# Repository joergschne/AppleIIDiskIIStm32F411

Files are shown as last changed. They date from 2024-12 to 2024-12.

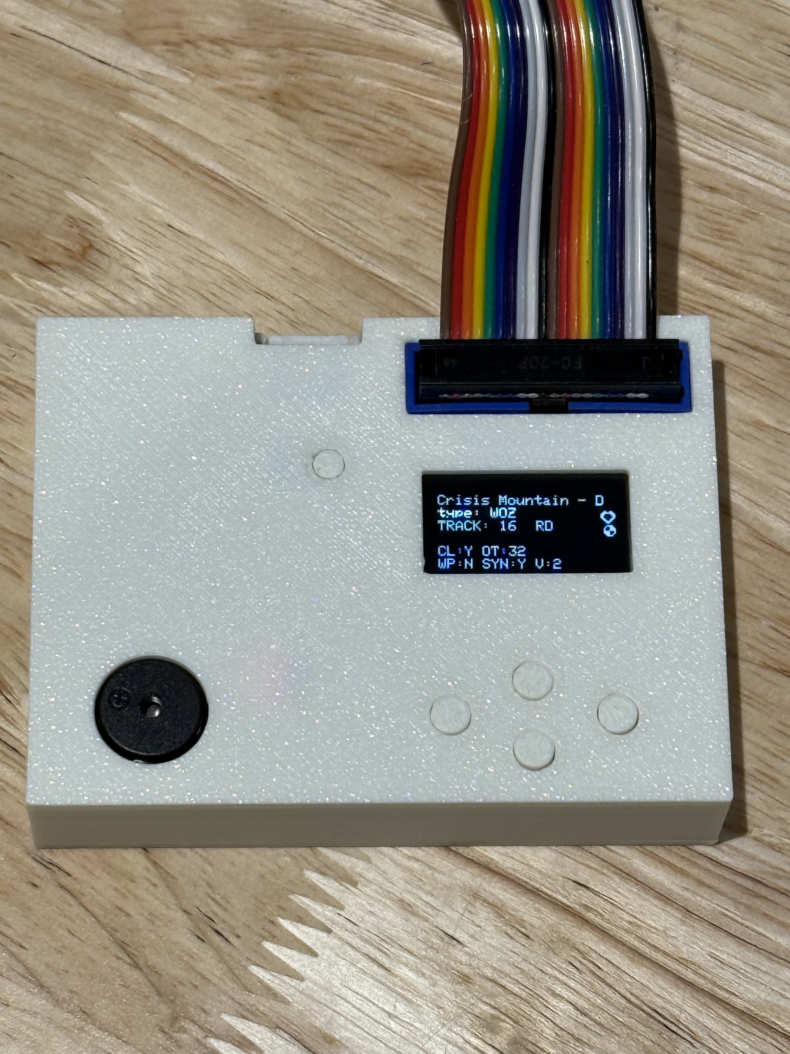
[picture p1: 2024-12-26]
resources/CASE.jpeg

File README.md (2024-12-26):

# SmartDisk II for Apple II

## Apple II STM32 based Hardware DISKII EMULATOR

This project is about an Apple II Disk II hardware emulator capable of reading / writing disk image from/to SDCARD.

This hardware emulator tries to replicate the behaviour of a real DISK II and thus should pass the copy protection on guenine disk images.

The project is still in beta mode, progress thread is on [AppleFritter Apple II Disk emulator using STM32]( https://www.applefritter.com/content/apple-ii-disk-emulator-using-stm32).



** If you decide to build one, please note that hardware design might evolve and new software releases might not work with the current hardware design. ** 
 
This project relies on a STM32F411(BlackPill) with SDIO Port.

## Project structre ##

| Directory | Description  |
|:---|:---|
|  ./gerber  | gerber release to produce PCB |
| ./hardware | kicad project |
| ./core | firmware source code |
| ./Middleware | libraries used |
| ./FATFS | fatfs wrapper  |
| ./doc | documentation used as reference  |
| ./3DPrintCase | 3D print file & Fusion 360 source to print case  |

## IMPORTANT NOTE ##

The ST-Link programmer should never be connected at the same time with either USB or the Apple II. The ST-link has some very fragile voltage regulator. 

The J1 PWR located at top right of the PCB enable +5V from the Apple II to the STM32.

Regarding the OLED Screen: becareful of the Power pins order, some version have pin inversed

R1,R2,R3 are not needed.

Before hardware Rev 3 the board is not compatible with IIGS & IIC, trace between IDC pin 5 & 7 needs to be cut

## <!> SDCARD <!> ##

The SDCard must use FAT32 file system must use 64 Sectors of 512 Byte each per cluster.

to format the SDCard under linux use the following command: 

`mkfs.fat -F 32 -s 64 `

Please be careful, Window 10/11 is not formatting the SDCard the right way. 

An config menu option is provided directly in the SmartDisk II to format the SDCard

## Main Features ##

The list of features currently supported in this project:
- Read the content of the SDCard and display the list of images on a 0.96 OLED display based of the ss1306.
- Mount / unmount disk image
- Read mounted image file on Apple II
- Write (experimental)





### Supported Emulation:
| Emulation  | Status
|:---  |:-----|
| DISK II 5.25| YES |
| SMARTPORT HD| YES |

### Supported disk image format:

| format  | read | write |
|:---  |:-----|:---|
| NIC| YES | NO | 
| WOZ 1.0| YES | NO |
| WOZ 2.0| YES | Experimental|
| DSK | YES  | NO |
| PO | YES | NO |

### Copy protection status

| Copy Protection | Status  | 
|:---|:---|
| FAT Track | PASSED |
| Weak Bit  | PASSED | 
| Cross track sync  | PASSED | 
| Half track | PASSED | 
| Data Latch | PASSED | 
| Timing Bits | PASSED |
| E7 | PASSED | 
| Optimal Bit Timing <4uS | PASSED |
| Various Bit Counter | PASSED | 
| SpiraDisc | PASSED | 

## Status of the project ##

The first PCB and software are available for testing purpose only. 

## Release

There are 2 releases type :
- BIN : classic binary to be uploaded via stlink and starting at 0x08000000
- UF2 : first you need to upload via stlink the custom bootloader, and then using USB and double click on NRST button, you can easily drag and drop UF2 release file to the stm32. WARNING if using the bootloader, the flash memory from 0x0800000 to 0x80100000 will become read-only (you need to use st-tool to change the stm32 register to reverse).

## What is coming next ## 

- Creation of a PCB with the STM32 chip directly,
- add root panel and config panel
- Add mkfs in the config panel
- Addition of protection to 20 pin connector inversion,
- Support of dsk,po image format for reading,
- Support of nic,woz 1.x -> 2.1 for writing,
- configuration screen,
- adding USB & UF2 bootlooder firmware update support,
- Remove STM HAL (High Level) driver and move to low level,
- Finalize a stable software.

## Hardware design main principles: ##

- The STM32F4x is preferred compared to the STM32F1 due to CPU Freq, available SRAM >60 kB and for the STM32F411 the use of SDIO. On this project timing is really critical, especially to pass some copy protection.

A DISK II floppy track is about 50.000 Bits, and to be able to read some of the floppy shifting from one track to another should respect some very specific rules.

- After many, many, many iterations and design tests, I decided to use a single track load in memory and to have SDCARD Data Read/Write using a 4bit SDIO port for speed. This way, there is no adjacent track management and complex buffer copy with internal index along with DMA interrupt. The constraints is to use very fast loading capability of the SDIO port (SPI works but with no containgency). 

- The Apple II is expecting data at a very precise pace 1 bit every 4 uS (32*125ns). Multiple options can be considered to perform this:
	- 1/ Using SPI with DMA
	- 2/ Assembly code with CPU cycle calculation & GPIO Bitbanging
	- 3/ Timer interrupt trigger with GPIO Bitbanging (preferred option)

The first option was my initial choice, very simple straight forward, and the CPU using DMA was completly free to do something else while sending data. One of the aspect of the SPI is to send 8 bits (1 Bytes) at a time. When using WOZ 1.0 and WOZ 2.0 the number of bits per track are not aligned with 8 and thus using SPI may (every time on a 36 track disk) introduce bit misalignement and corrupted data. There is no way to have WOZ copy protected image file to work using 8 Bits aligned data stream.

The second option was also tested and gives very poor reliability and was very quickly put aside.

The last one, using TIMER interrupt seems by far to be the best option and enable to free up CPU time to manage the OLED display updates and to other button interrupt. 
Each interrupt, the Read GPIO is bitbang according to the track stream position. The real advantage is to be able to address very easily some specific protection mecanism using fake bit tank. Using timer is also very easy to increase or reduce the space between 2 bit because some games use 3.8 uS instead of 4 uS. The trick is to manage other interrupt priority not to disturb the READ/WRITE Timer process.

- The approach for the writing process is pretty much the same as for the reading process, using a dedicated timer with an overflow every 4us. As writing uses polarity inversion, an internal software XOR is done instead of using external circuitery. Using the SDIO makes it also very easy timing wise to write to SDCard.  

Using this approach with Timers, there is no need to external circuitery and almost everything can be manage from a software standpoint (in the future I might add a 74LS125 to protect the STM32).

Main design on STM32:

Head positionning stepper, managed by external interrupts: 
  - PA0 STEP0, ExtI0
  - PA1 STEP1, ExtI1
  - PA2 STEP2, ExtI2
  - PA3 STEP3, ExtI3

Button: External Interrupt 9-15 with Timer4 as a debouncer
  - PC13 BTN_DOWN
  - PC14 BTN_UP
  - PC15 BTN_ENTR
  - PB12 BTN_RET

SDCARD: SDIO Port with a clock divider by 2 (to keep most of the SDCard working)
  - PB4 DO
  - PA8 D1
  - PA9 D2
  - PB5 D3
  - PA6 CMD
  - PB15 CK

I2C Oled Screen SSD1306
  - PB06 SCL
  - PB07 SDA

UART:
  - PA15 TX
  - PB3 RX

TIMERS:
- TIM2 Timer 2 : Use to Manage the WR_DATA, ETR1 Slave Reset mode to resync with the Apple II  Write Pulse that is 3.958 uS instead of 4uS. Every Rising Edge resync
- TIM3 Timer 3 : Use to Manage the RD_DATA, 
- TIM4 Timer 4 : Internal no PWM, debouncer for the control button

## BOM ## 

| Ref. | Type. |  Ref Supplier  |
|:---|:---|:---|
| Uc1 | STM32F411 (BlackPill) | Aliexpress WeAct Studio 3.0 STM32F411CEU6  |
| U2 | SDCard PushPush GCT MEM2055 / GCT MEM2075  | Mouser 640-MEM20750014001A / LCSC C381084  |
| U8 | SSD1315 I2C 128x64 0.96 OLED |  LCSC C5248080 |
| R1,R2,R3  | Resistor 1K (Optional)  1/4W L6.3mm_D2.5mm_P10.16mm  | Mouser 708-CFF14JT1K00 |
|J1|PWR|Pin Header_1x02 P2.54mm  |
|J2|Apple IDC 2x10P P2.54| LCSC C115249|
|J3|DBG|Pin Header_1x05 P2.54mm  |
|J4|UART|Pin Header_1x03 P2.54mm  |
|J5|TIM|Pin Header_1x03 P2.54mm  |
|J6|STLINK|Pin Header_1x04 P2.54mm  |
|DOWN1,ENTR1,RET1,UP1|6mm 5mm Round Button 50mA Direct Insert 6mm SPST 12V| LCSC C393938
|BZ1|Passive buzzer 12 x 6.0MM P6.5| LCSC C252917

## Software design main principles: ##

The current software version rely on :
- STM32 HAL Driver from STMicro
- FATFS 0.15 (becareful STCUBEMX32 override to version 0.11)
- CJOSN for configuration file (with some tweaks to make FATFS working)
- SSD1306 Lib with DMA

Software Architecture: 

the maximum track size is 13*512*8= 53 248 Bits or 6656 Bytes

2 Unsigned char Buffers are used :
- DMA_BIT_TX_BUFFER[6656];   	// For reading part     
- DMA_BIT_RX_BUFFER[6656];		// For writing part

weakBitTank uint_8 array & fakeBitTank char array are used to manage some copy protection mecanism

### Important Functions ### 

- void TIM3_IRQHandler: Manage the Bitbang of the GPIO port to send track data every 4us (or less depending on the WOZ file configuration) to the Apple II

- void void TIM2_IRQHandler: Manage the data sent from the Apple II for the writing process. It use a software XOR to detect polarity inversion and write 1 or 0 to the DMA_BIT_RX_BUFFER.

- void irqReadTrack: Configure interrupt for Reading 
- void irqWriteTrack: Configure interrupt for Writing

- void getDataBlocksBareMetal(long memoryAdr,volatile unsigned char * buffer,int count): Instead of using FATFS function such as F_OPEN, using direct access to the SDCard using the SDIO port to receive data is faster.

- void setDataBlocksBareMetal(long memoryAdr,volatile unsigned char * buffer,int count): same for the writing process, faster than using FATFS

<!> keep in mind that even if FATFS is not used to read and write to the SDCARD data from/to the Apple II, FATFS is needed to build up the File Allocation Table with the right file address block.

- void processDeviceEnableInterrupt: Interrrupt function used when Apple II change signal on DEVICE_ENABLE PIN to activate or deactivate the DISKII Drive. This signal is active LOW

- void processBtnInterrupt: Manage the 4 BTN press

- void processDiskHeadMoveInterrupt(uint16_t GPIO_Pin): Interrupt function link to the 4 GPIO Stepper motor of the DISKII.

- Main () is orchestring the program execution. 

Please note that you will need to have a STLINK32 to upload the firmware to the STM32F411



## Recommanded reading 

- Woz 2.1 Image file reference
- Woz 1.0 Image file reference
- Tome of copy protection
- Beneath Apple DOS
- Assembly lines
- Understanding the Apple II 
- PoC|GFTO_issue10
- PoC|GFTO_issue11

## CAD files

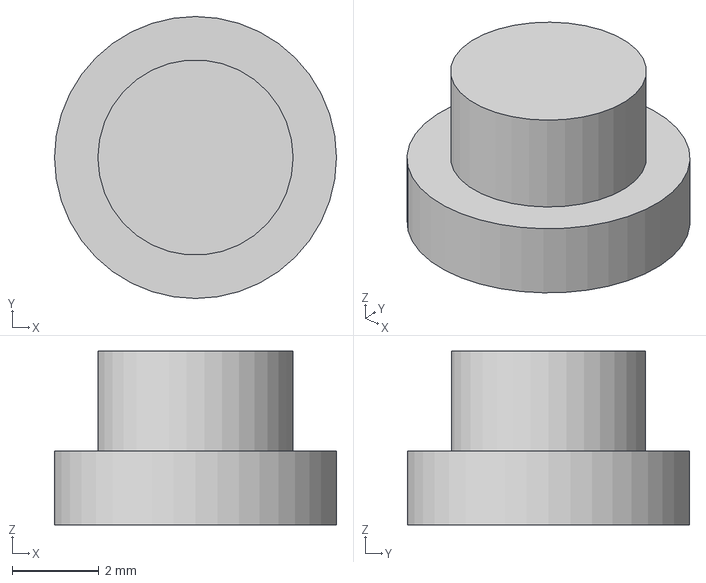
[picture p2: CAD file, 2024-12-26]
3DPrintCase/SmartDiskII button v18.3mf
6.50 x 6.50 x 4.00 mm

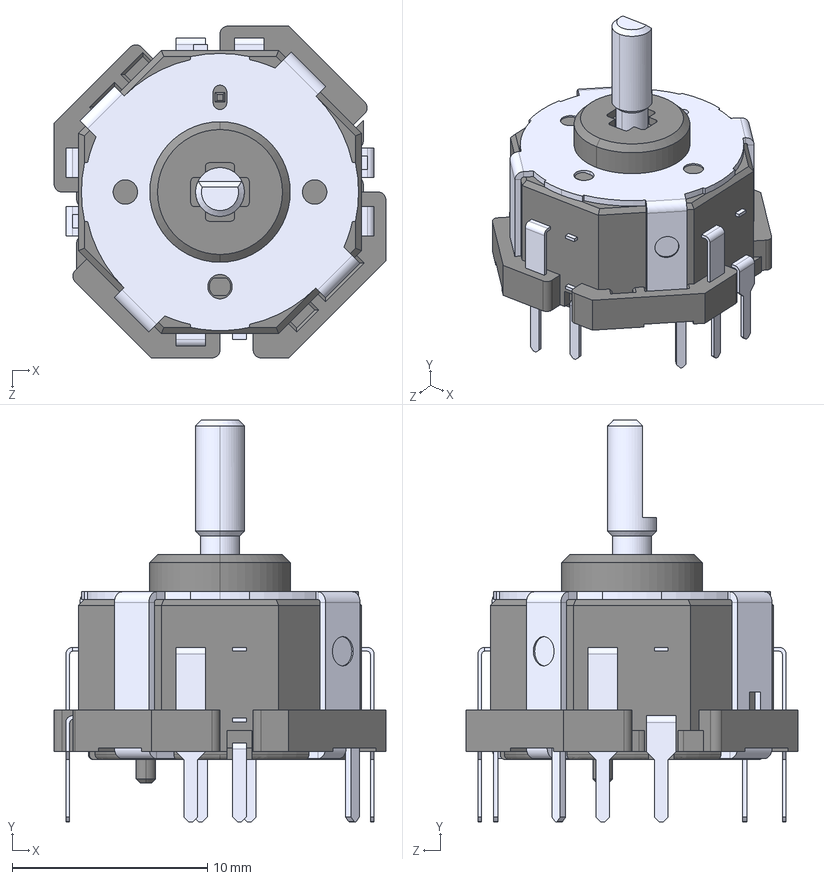
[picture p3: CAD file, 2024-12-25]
Contribute/A2F-Hardware/cad/RKJXT1F42001.step
17.0 x 20.6 x 17.0 mm

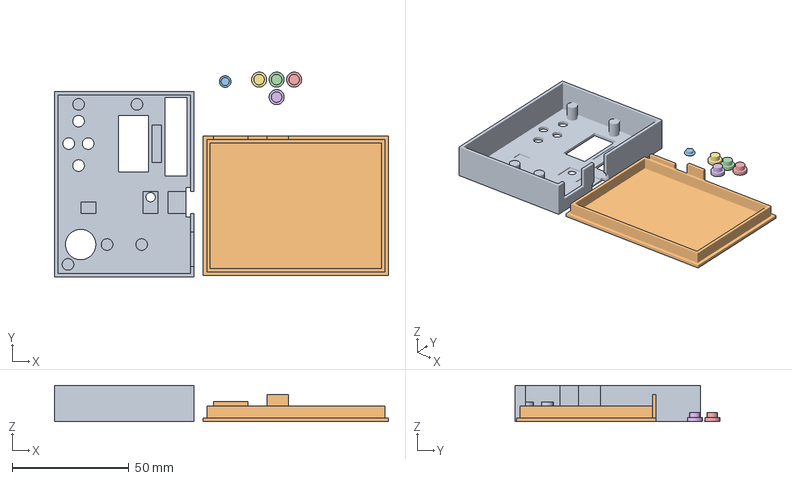
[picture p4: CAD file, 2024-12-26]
3DPrintCase/SmartDiskII Bambulab prj.3mf
142.9 x 87.7 x 15.5 mm
SmartDiskII bottom v18b
couvercle
bouton RESET
bouton x 4

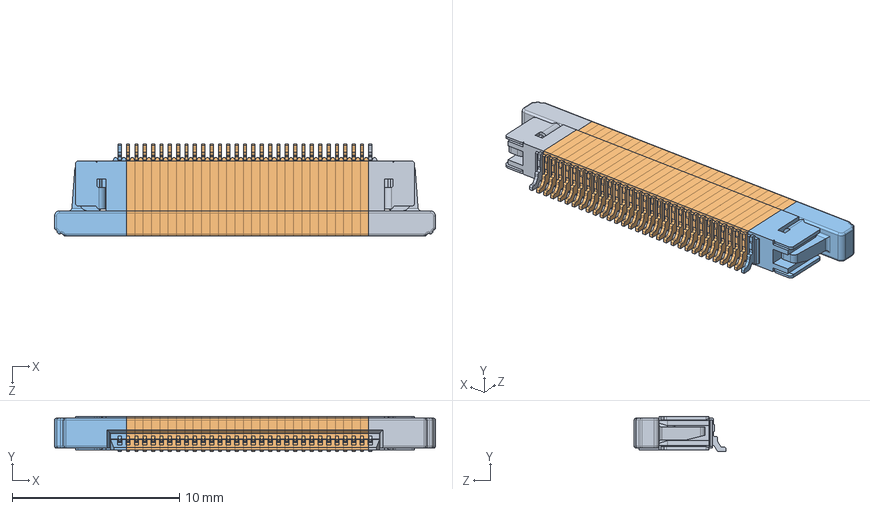
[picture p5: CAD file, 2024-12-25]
Contribute/A2F-Hardware/cad/F32R-1A7H1-11031.step
22.8 x 2.10 x 5.50 mm
F32R_R.STEP
F32R_M.STEP x 29
F32R_L.STEP

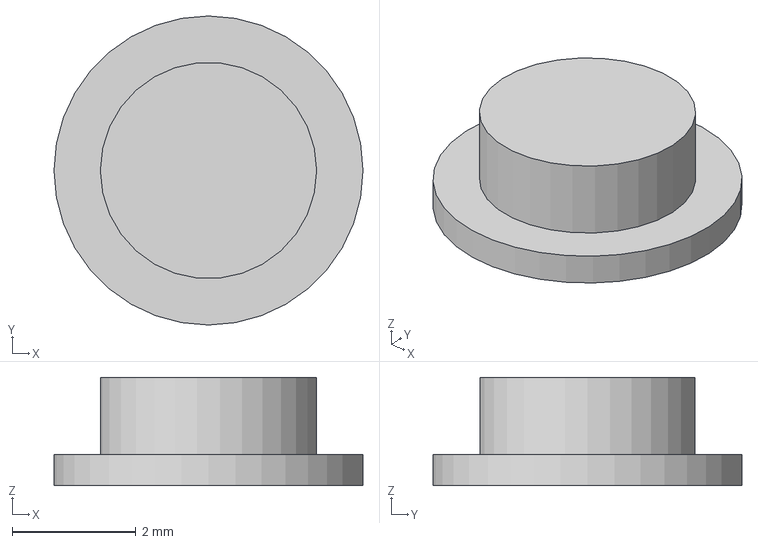
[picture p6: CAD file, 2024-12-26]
3DPrintCase/SmartDiskII button reset v18.3mf
5.00 x 5.00 x 1.75 mm

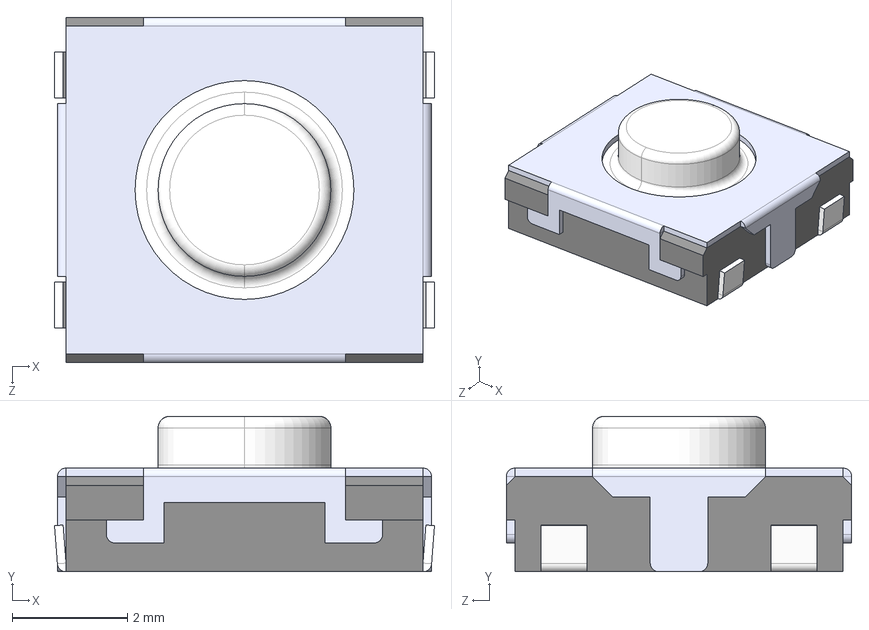
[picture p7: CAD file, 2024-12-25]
Contribute/A2F-Hardware/cad/EVQ-Q2B02W.step
6.60 x 2.70 x 6.00 mm

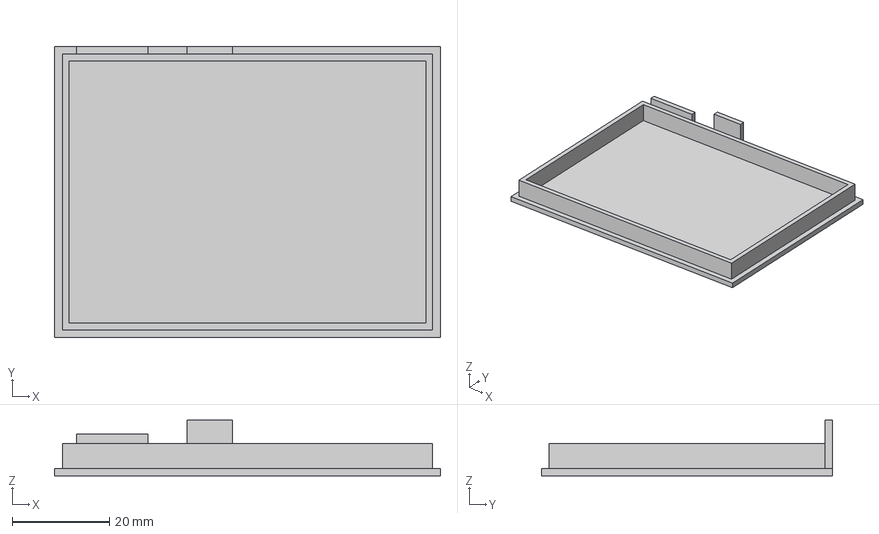
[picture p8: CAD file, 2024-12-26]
3DPrintCase/SmartDiskII top v18.3mf
79.3 x 59.8 x 11.5 mm

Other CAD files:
3DPrintCase/SmartDiskII bottom v18.3mf
3DPrintCase/SmartDiskII Case v18.f3d

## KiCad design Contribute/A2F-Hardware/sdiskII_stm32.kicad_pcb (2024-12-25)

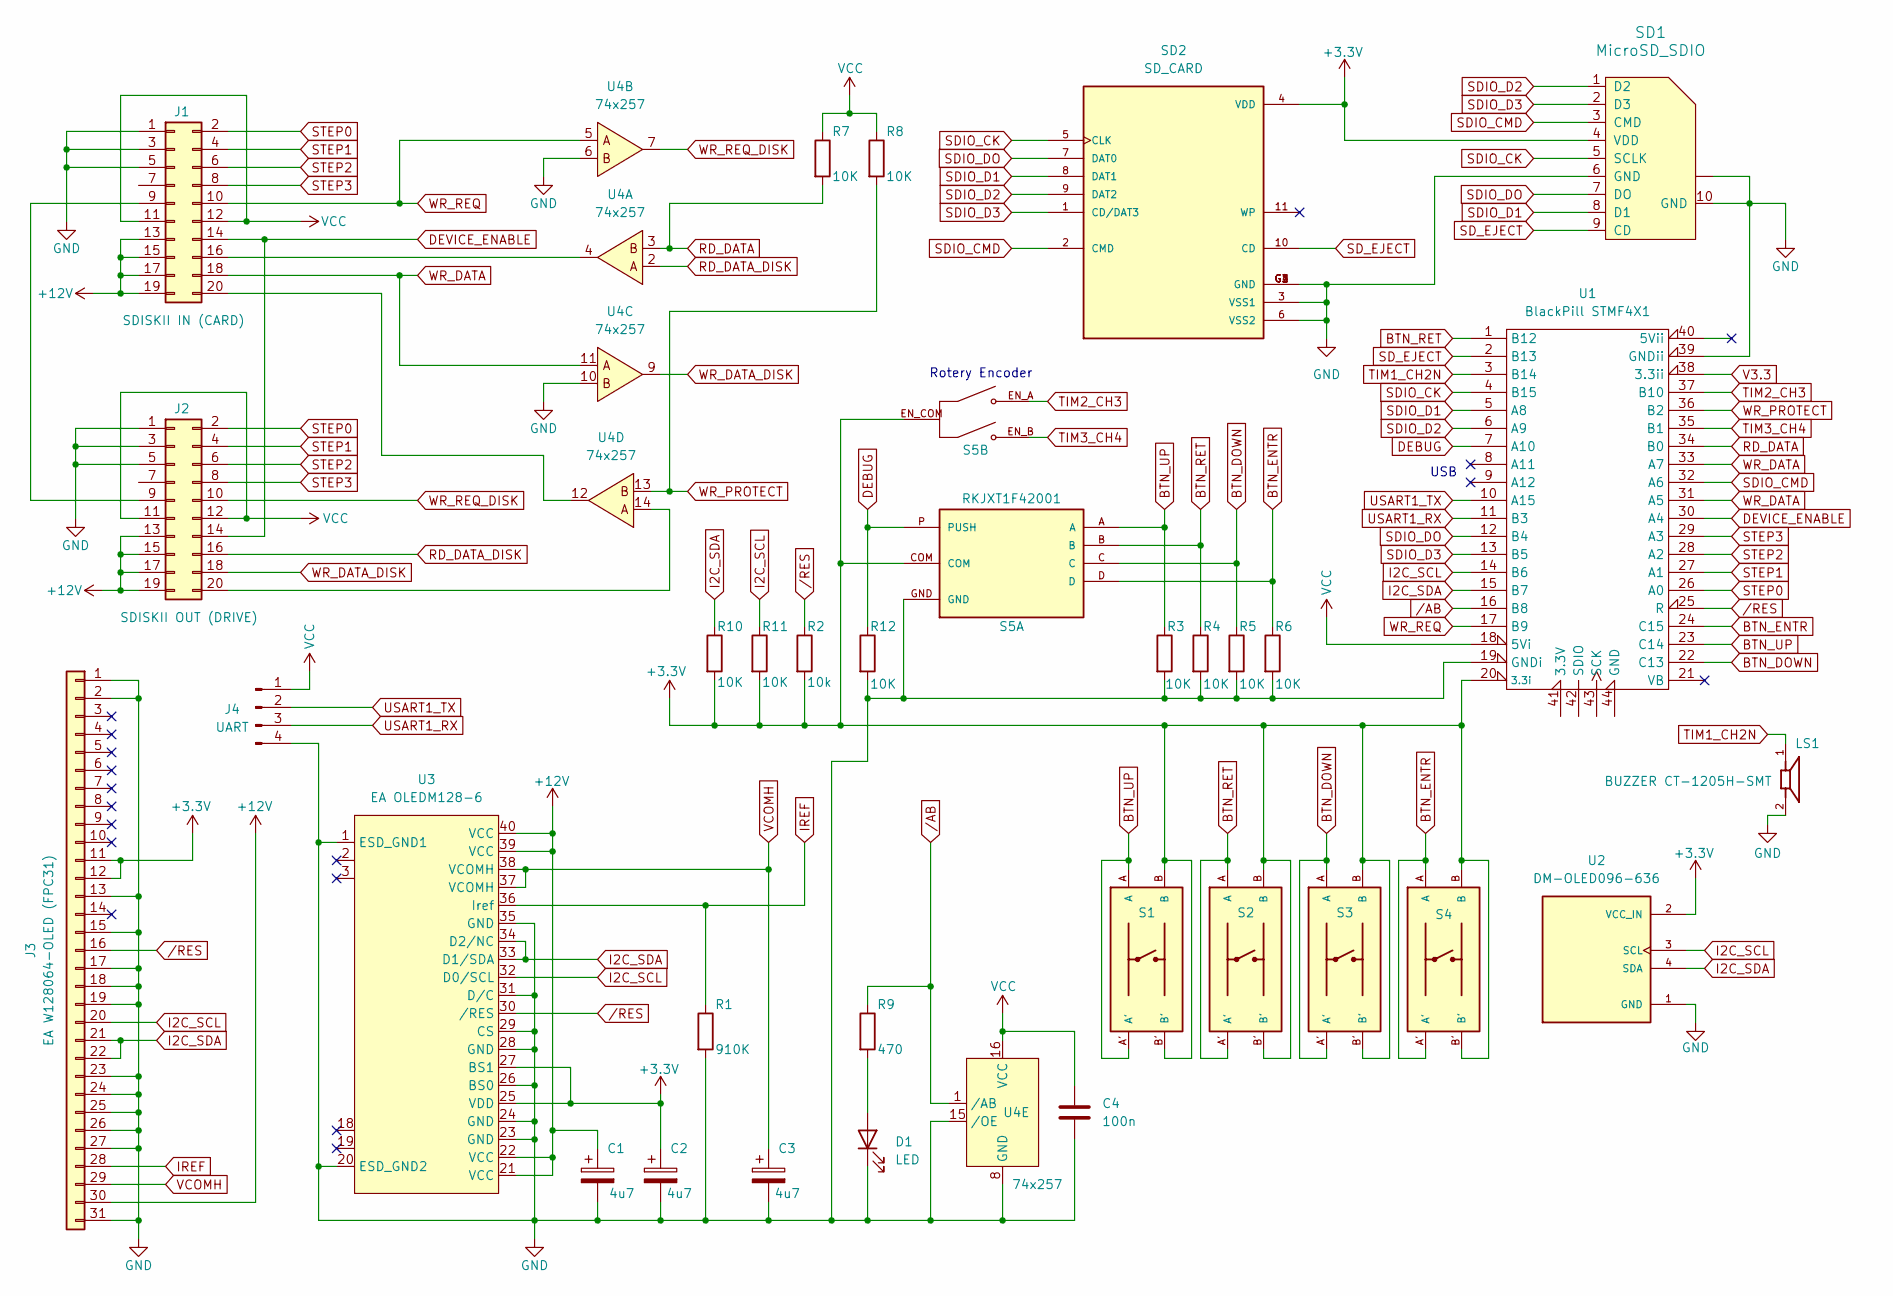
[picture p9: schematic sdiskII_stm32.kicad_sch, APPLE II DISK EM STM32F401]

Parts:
C1, C2, C3: 4u7; CP_EIA-3216-18_Kemet-A_Pad1.58x1.35mm_HandSolder
C4: 100n; C_0805_2012Metric_Pad1.18x1.45mm_HandSolder
D1: LED; LED_D3.0mm
J1: SDISKII IN (CARD); IDC-Header_2x10_P2.54mm_Vertical
J2: SDISKII OUT (DRIVE); IDC-Header_2x10_P2.54mm_Vertical
J3: EA W128064-OLED (FPC31); AMPHENOL_F32R-1A7H1-11031
J4: UART; PinHeader_1x04_P2.54mm_Vertical
LS1: BUZZER CT-1205H-SMT; BUZZER CUI_CT-1205H-SMT; PART_REV 1.02
R1: 910K; R_0805_2012Metric_Pad1.20x1.40mm_HandSolder
R2: 10k; R_0805_2012Metric_Pad1.20x1.40mm_HandSolder
R3, R4, R5, R6, R7, R8, R10, R11, R12: 10K; R_0805_2012Metric_Pad1.20x1.40mm_HandSolder
R9: 470; R_0805_2012Metric_Pad1.20x1.40mm_HandSolder
S1, S2, S3, S4: EVQ-Q2B02W; SW_EVQ-Q2B02W
S5: RKJXT1F42001; ALPS XDCR_RKJXT1F42001
SD1: MicroSD_SDIO; GCT-MEM2055-00-190-01-A_VIB
SD2: SD_CARD; SD_CARD_AMPHENOL_GMC020080HR; PARTREV AX6
U1: BlackPill STMF4X1; Mini_F4X1_STM32_VIB
U2: DM-OLED096-636; MODULE_DM-OLED096-636-SMAL; PARTREV 2018-09-10
U3: EA OLEDM128-6
U4: 74x257; SOIC-16_3.9x9.9mm_P1.27mm

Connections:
+3.3V: C2.1, J3.11, J3.12, R2.2, R10.2, R11.2, S1.B, S1.B', S2.B, S2.B', S3.B, S3.B', S4.B, S4.B', S5.COM, S5.EN_COM, SD1.4 (VDD), SD2.4 (VDD), U1.20 (3.3i), U2.2 (VCC_IN), U3.25 (VDD), U3.27 (BS1)
+12V: C1.1, J1.13, J1.15, J1.17, J1.19, J2.13, J2.15, J2.17, J2.19, J3.30, U3.21 (VCC), U3.22 (VCC), U3.39 (VCC), U3.40 (VCC)
BTN_DOWN: R5.1, S3.A, S3.A', S5.C, U1.22 (C13)
BTN_ENTR: R6.1, S4.A, S4.A', S5.D, U1.24 (C15)
BTN_RET: R4.1, S2.A, S2.A', S5.B, U1.1 (B12)
BTN_UP: R3.1, S1.A, S1.A', S5.A, U1.23 (C14)
DEBUG: R12.1, S5.P (PUSH), U1.7 (A10)
DEVICE_ENABLE: J1.14, J2.14, U1.30 (A4)
GND: C1.2, C2.2, C3.2, C4.2, D1.1 (K), J1.1, J1.3, J1.5, J1.7, J2.1, J2.3, J2.5, J2.7, J3.1, J3.2, J3.13, J3.15, J3.17, J3.18, J3.19, J3.23, J3.24, J3.25, J3.26, J3.27, J3.31, J4.4, LS1.2, R1.2, R3.2, R4.2, R5.2, R6.2, R12.2, S5.GND, SD1.6 (GND), SD1.10 (GND), SD1.~, SD2.3 (VSS1), SD2.6 (VSS2), SD2.G1 (GND), SD2.G2 (GND), SD2.G3 (GND), SD2.G4 (GND), U1.19 (GNDi), U1.39 (GNDii), U2.1 (GND), U3.1 (ESD_GND1), U3.20 (ESD_GND2), U3.23 (GND), U3.24 (GND), U3.26 (BS0), U3.28 (GND), U3.29 (CS), U3.31 (D/C), U3.35 (GND), U4.6, U4.8 (GND), U4.10, U4.15 (/OE)
I2C_SCL: J3.20, R11.1, U1.14 (B6), U2.3 (SCL), U3.32 (D0/SCL)
I2C_SDA: J3.21, J3.22, R10.1, U1.15 (B7), U2.4 (SDA), U3.33 (D1/SDA), U3.34 (D2/NC)
IREF: J3.28, R1.1, U3.36 (Iref)
unnamed: D1.2 (A), R9.2
unnamed: J1.9, J2.9
unnamed: J1.16, U4.4
unnamed: J1.20, U4.12
unnamed: J2.20, U4.14
RD_DATA: R7.2, U1.34 (B0), U4.3
RD_DATA_DISK: J2.16, U4.2
SDIO_CK: SD1.5 (SCLK), SD2.5 (CLK), U1.4 (B15)
SDIO_CMD: SD1.3 (CMD), SD2.2 (CMD), U1.32 (A6)
SDIO_D1: SD1.8 (D1), SD2.8 (DAT1), U1.5 (A8)
SDIO_D2: SD1.1 (D2), SD2.9 (DAT2), U1.6 (A9)
SDIO_D3: SD1.2 (D3), SD2.1 (CD/DAT3), U1.13 (B5)
SDIO_DO: SD1.7 (DO), SD2.7 (DAT0), U1.12 (B4)
SD_EJECT: SD1.9 (CD), SD2.10 (CD), U1.2 (B13)
STEP0: J1.2, J2.2, U1.26 (A0)
STEP1: J1.4, J2.4, U1.27 (A1)
STEP2: J1.6, J2.6, U1.28 (A2)
STEP3: J1.8, J2.8, U1.29 (A3)
TIM1_CH2N: LS1.1, U1.3 (B14)
TIM2_CH3: S5.EN_A, U1.37 (B10)
TIM3_CH4: S5.EN_B, U1.35 (B1)
USART1_RX: J4.3, U1.11 (B3)
USART1_TX: J4.2, U1.10 (A15)
V3.3: U1.38 (3.3ii)
VCC: C4.1, J1.11, J1.12, J2.11, J2.12, J4.1, R7.1, R8.1, U1.18 (5Vi), U4.16 (VCC)
VCOMH: C3.1, J3.29, U3.37 (VCOMH), U3.38 (VCOMH)
WR_DATA: J1.18, U1.31 (A5), U1.33 (A7), U4.11
WR_DATA_DISK: J2.18, U4.9
WR_PROTECT: R8.2, U1.36 (B2), U4.13
WR_REQ: J1.10, U1.17 (B9), U4.5
WR_REQ_DISK: J2.10, U4.7
/AB: R9.1, U1.16 (B8), U4.1 (/AB)
/RES: J3.16, R2.1, U1.25 (R), U3.30 (/RES)

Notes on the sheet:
USB
Rotery Encoder

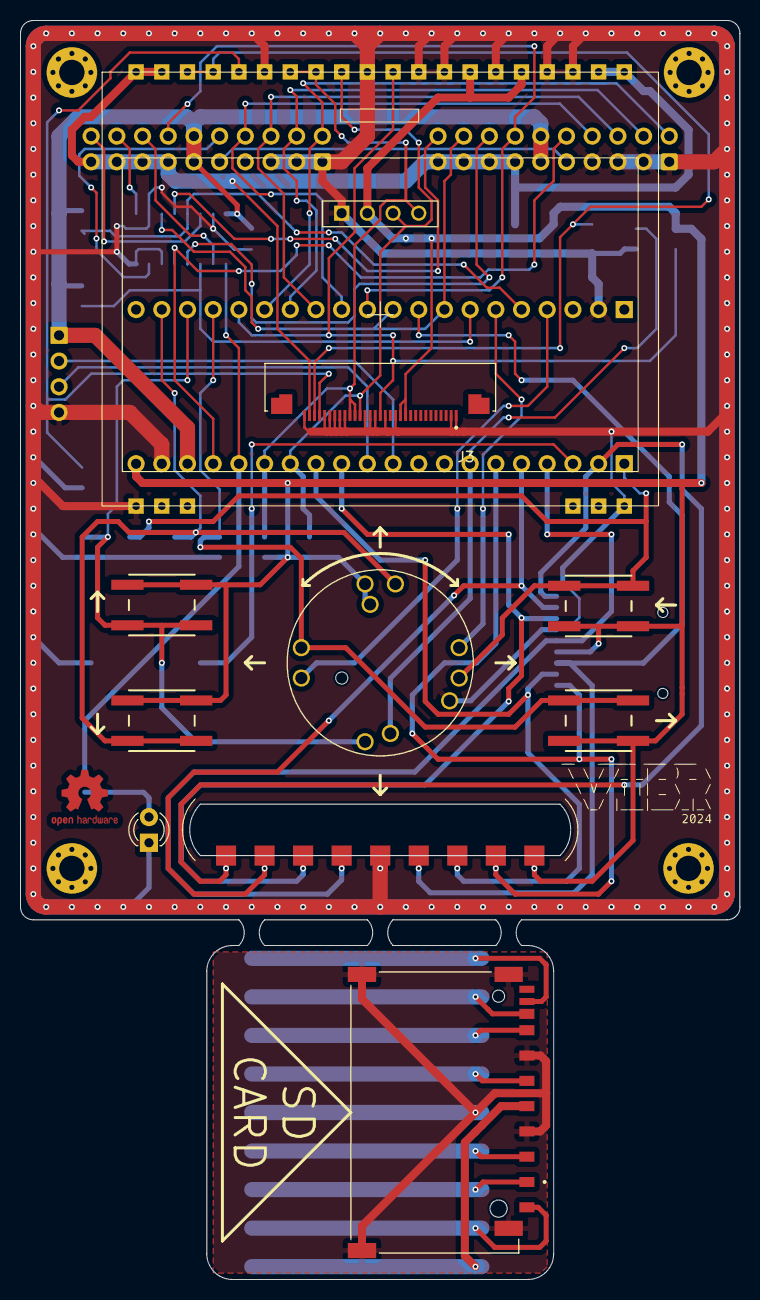
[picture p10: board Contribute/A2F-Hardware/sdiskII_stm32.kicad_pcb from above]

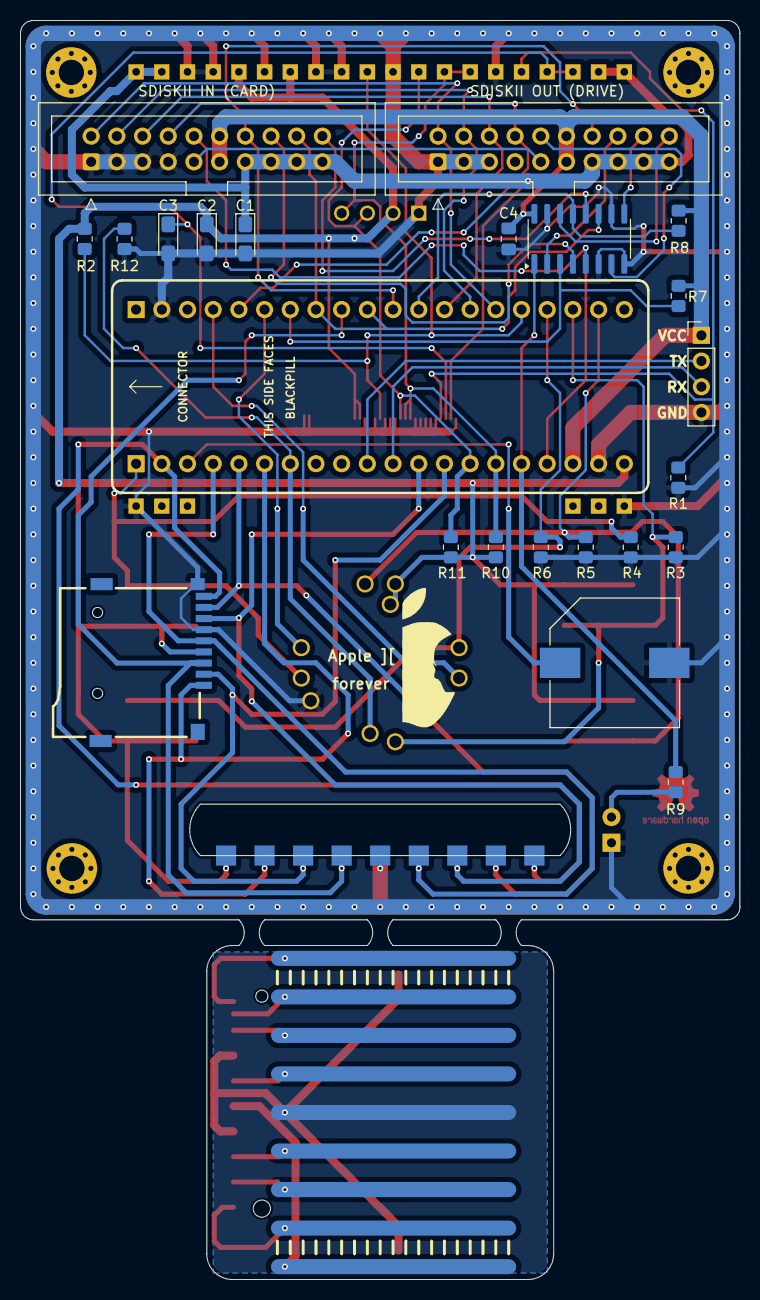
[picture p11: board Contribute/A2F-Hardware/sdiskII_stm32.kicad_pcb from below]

Board: 2 copper layers, 71.1 x 124.5 mm, 38 parts (23 on the bottom side), 44 nets.

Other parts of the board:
H1, H2, H3, H4: MountingHole_2.5mm_Pad_Via
VIBR: LOGO

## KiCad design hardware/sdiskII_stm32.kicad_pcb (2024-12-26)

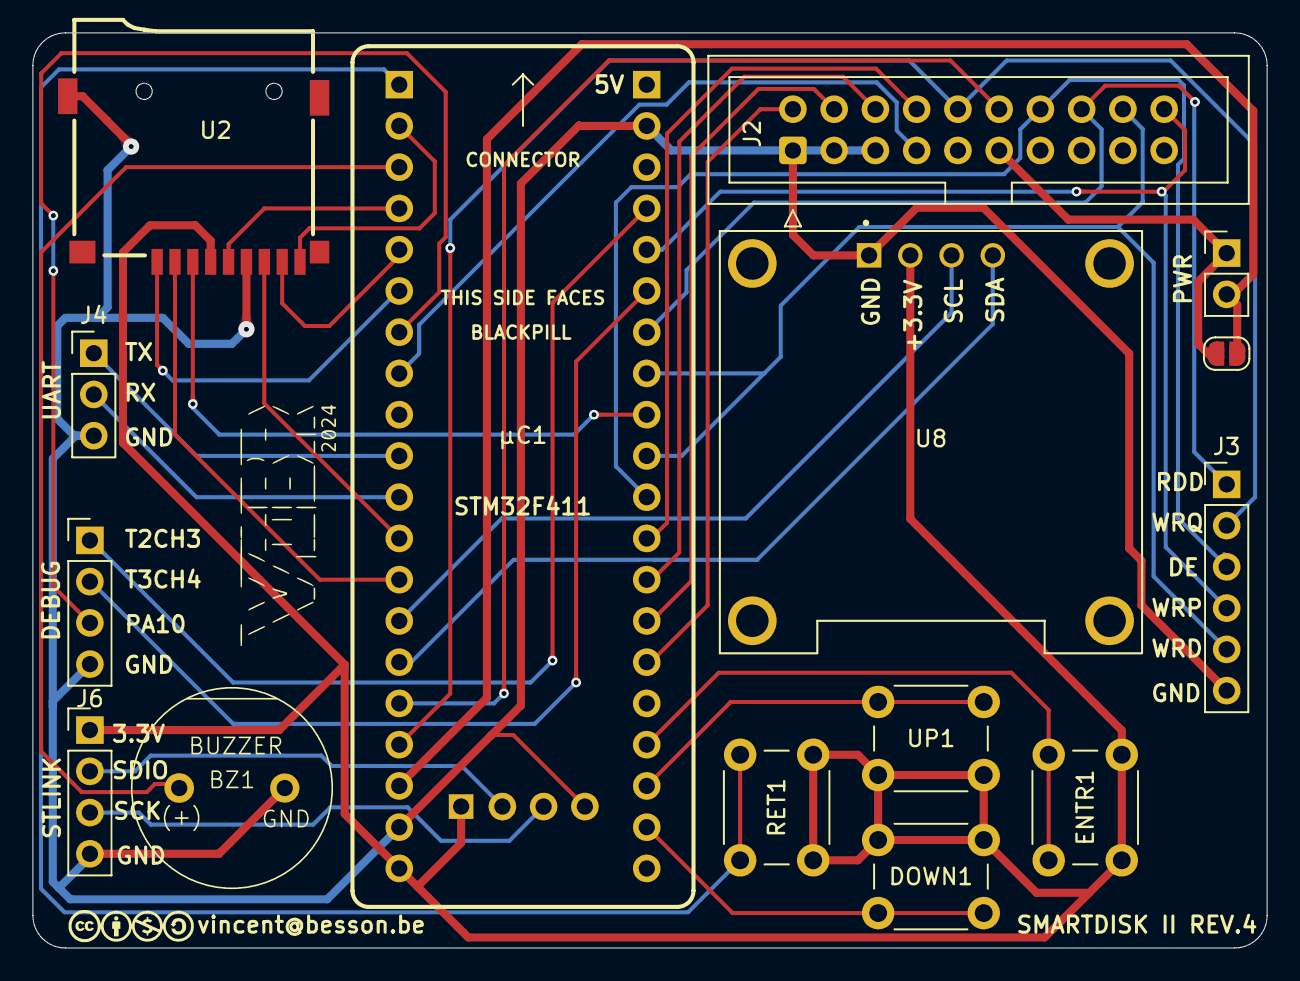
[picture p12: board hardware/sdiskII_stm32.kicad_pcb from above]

Board: 2 copper layers, 76.0 x 56.3 mm, 17 parts (0 on the bottom side), 36 nets.

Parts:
 : LOGO
 #2: LOGO
BZ1: Buzzer; AS-1201B-LF
DEBUG: Conn_01x04; PinHeader_1x04_P2.54mm_Vertical
DOWN1: SW_Push; SW_PUSH_6mm
ENTR1: SW_Push; SW_PUSH_6mm
J1: PWR; PinHeader_1x02_P2.54mm_Vertical
J2: APPLE_SDISKII; IDC-Header_2x10_P2.54mm_Vertical
J3: Conn_01x06; PinHeader_1x06_P2.54mm_Vertical
J4: UART; PinHeader_1x03_P2.54mm_Vertical
J6: STLINK; PinHeader_1x04_P2.54mm_Vertical
JP1: SPST; SolderJumper-2_P1.3mm_Open_RoundedPad1.0x1.5mm
RET1: SW_Push; SW_PUSH_6mm
U2: MicroSD_SDIO; GCT-MEM2055-00-190-01-A_VIB
U8: DM-OLED096-636; MODULE_DM-OLED096-636
UP1: SW_Push; SW_PUSH_6mm
μC1: BlackPill STMF4X1; Mini_F4X1_STM32_VIB

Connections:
3.5DSK: J2.7, μC1.8 (A11)
+3.3V: DOWN1.1, ENTR1.1, J6.1, RET1.1, U2.4 (VDD), U8.2 (VCC_IN), UP1.1, μC1.20 (3.3i), μC1.41 (3.3V)
BTN_DOWN: DOWN1.2, μC1.22 (C13)
BTN_ENTR: ENTR1.2, μC1.24 (C15)
BTN_RET: RET1.2, μC1.1 (B12)
BTN_UP: UP1.2, μC1.23 (C14)
DEBUG: DEBUG.3, μC1.7 (A10)
DEVICE_ENABLE: J2.14, J3.3, μC1.30 (A4)
GND: BZ1.2 (-), DEBUG.4, J2.1, J2.3, J2.5, J3.6, J4.3, J6.4, U2.6 (GND), U2.10 (GND), U2.~, U8.1 (GND), μC1.19 (GNDi), μC1.39 (GNDii), μC1.44 (GND)
I2C_SCL: U8.3 (SCL), μC1.14 (B6)
I2C_SDA: U8.4 (SDA), μC1.15 (B7)
PWR_IN: J1.2, JP1.1 (A), μC1.18 (5Vi)
RD_DATA: J2.16, J3.1, μC1.34 (B0)
SCK: J6.3, μC1.43 (SCK)
SDIO: J6.2, μC1.42 (SDIO)
SDIO_CK: U2.5 (SCLK), μC1.4 (B15)
SDIO_CMD: U2.3 (CMD), μC1.32 (A6)
SDIO_D1: U2.8 (D1), μC1.5 (A8)
SDIO_D2: U2.1 (D2), μC1.6 (A9)
SDIO_D3: U2.2 (D3), μC1.13 (B5)
SDIO_DO: U2.7 (DO), μC1.12 (B4)
SD_EJECT: U2.9 (CD), μC1.2 (B13)
SELECT: J2.12, μC1.16 (B8)
STEP0: J2.2, μC1.26 (A0)
STEP1: J2.4, μC1.27 (A1)
STEP2: J2.6, μC1.28 (A2)
STEP3: J2.8, μC1.29 (A3)
TIM1_CH2N: BZ1.1 (+), μC1.3 (B14)
TIM2_CH3: DEBUG.1, μC1.37 (B10)
TIM3_CH4: DEBUG.2, μC1.35 (B1)
USART1_RX: J4.2, μC1.11 (B3)
USART1_TX: J4.1, μC1.10 (A15)
VCC: J1.1, J2.11, JP1.2 (B)
WR_DATA: J2.18, J3.5, μC1.31 (A5), μC1.33 (A7)
WR_PROTECT: J2.20, J3.4, μC1.36 (B2)
WR_REQ: J2.10, J3.2, μC1.17 (B9)

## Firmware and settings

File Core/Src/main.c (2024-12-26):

/* USER CODE BEGIN Header */
/*
__   _____ ___ ___        Author: Vincent BESSON
 \ \ / /_ _| _ ) _ \      Release: 0.79
  \ V / | || _ \   /      Date: 2024.12.22
   \_/ |___|___/_|_\      Description: Apple Disk II Emulator on STM32F4x
                2024      Licence: Creative Commons
______________________


Todo:
- Add the screen PWR on a pin and not directly on the +3.3V
- Add 74LS125 to protect the STM32 against AII over current
- Add .2Mg file support
- Add feature request from Retro-Device A / B Head positioning 
- Adding on PCB jumper solder
- Adding on PCB Power Pin 11


Note 
+ CubeMX is needed to generate the code not included such as drivers folders and ...
+ An update of fatfs is required to manage long filename otherwise it crashes, v0.15 
+ stm32f411 blackpill v3 if SDIO Sdcard Management otherwise, any STM32fx would work with SPI / DMA,
+ Adding a manual procedure to simulate the headsync with noise

Navigation:
- Config items:
  - makefs
  - boot last or boot favorite
  - fs save current dir
  - wipe favorites
  - wipe config
  
Lessons learned:
- Warning screen update with DMA while SDIO is running can perform SDIO error
- When SDIO appears one way is to investigate is to disable all interrupt & renable one by one
- Using a clock divider is also helping, clockDIV by 2 is solving the SDCard issue
- SDCard need to be formated with 64 sectors of 512 Bytes each / cluster mkfs.fat -F 32 -s64 
- SDCard CMD17 is not fast enough due to wait before accessing to the bloc (140 CPU Cycle at 64 MHz), prefer CMD18 with multiple blocs read,

- Bitstream output is made via DMA SPI (best accurate option), do not use baremetal bitbanging with assemnbly (my first attempt) it is not accurate in ARM with internal interrupt,
- Use Interrupt for head move on Rising & Falling Edge => Capturing 1/4 moves
- Warning Bootloader might take too much time to load and thus missing the headsync procedure,

Current status: READ PARTIALLY WORKING / WRITE Experimental
+ Woz file support : in progress first images are working
+ NIC file support : in progress first images are working

"tasks": [
			{
				"label": "FatFs CleanUP",
				"type": "shell",
				"command": "cd ./Middlewares/Third_Party/FatFs; pwd; dir; /bin/bash ./r015.sh",
				"options": {
					"cwd": "${workspaceRoot}"
				},
				"group": {
					"kind": "build",
					"isDefault": true
				},
				"problemMatcher": [
					"$gcc"
				]
			},

Architecture:
- TIM1 Timer 1 : Use to Manage passive buzzer on PIN 14 (Channel 2N), via a PWM 
- TIM2 Timer 2 : Use to Manage the WR_DATA, ETR1 Slave Reset mode to resync with the A2 Write Pulse that is 3.958 uS instead of 4uS. Every Rising Edge resync
- TIM3 Timer 3 : Use to Manage the RD_DATA, 
- TIM4 Timer 4 : Internal no PWM, debouncer for the control button

GPIO

BTN
  - PC13 BTN_DOWN
  - PC14 BTN_UP
  - PC15 BTN_ENTR
  - PB12 BTN_RET

STEP
  - PA0 STEP0
  - PA1 STEP1
  - PA2 STEP2
  - PA3 STEP3

  - PB09 WR_REQ
  - PB02 WR_PROTECT
  - PA04 DEVICE_ENABLE
  - PA13 SD_EJECT

SDIO
  - PB4 DO
  - PA8 D1
  - PA9 D2
  - PB5 D3
  - PA6 CMD
  - PB15 CK

I2C Screen SSD1306
  - PB06 SCL
  - PB07 SDA

UART
  - PA15 TX
  - PB3 RX

*/ 

// Changelog
/*
26.12.24 v0.79.2 
  + Add Boot image index for Smartport

26.12.24 v0.79.1
  +Remove hardcoded emulation type
13.12.24  v0.79
  +Fix: complete code restructuring to enable different emulation type
  +Feat: Add Smartport HD emulation type
  +Feat: Add Config menu to manage emulation type
  +Feat: Manage physical head positioning for Disk A & B
25.11.24: v0.78.4
  +Feat: Locksmith Certify works and Fast copy also
25.11.24: v0.78.3
  +Feat: makefs in the menu config
  +Fix: compilation option for fatfs mkfs
  +Fix : add fatfs label option
  +Feat: add confirmation question on mkfs from menu config
  +Fix: variable casting uint8 instead of int in getConfigParamUInt8
  +Fix: Empty SDCard crash, sortlst check for empty chainedlist
  +Feat: writing part 1 setting the woz driver function
  +Feat: writing part 2 correct write bitstream and fix bit shift
24.11.24: v0.78.2
  +Fix: bootloader delay providing a coldstart issue on several images
23.11.24: v0.78.1
  +Fix: Spiradisc fix, screenupdate was before memcopy was generation an extra delay and thus failing with cross track sync
22.11.24: v0.78
  +fix: WOZ more than 40 trk disk such as lode runner, add Max TRK
22.11.24: v0.77
  +fix: DSK reading, wrong NIBBLE_BLOCK_SIZE from 512 to 416
  +fix: NIC reading, wrong NIBBLE_BLOCK_SIZE from 512 to 416
20.11.24: v0.76
  +fix: weakbit issue, changing the threshold to 4 (instead of 2), Bouncing Kamungast is working
  +fix: weakbit the Print shop is now working, wrong variable used
  +fix: buzzer sound change after button is pressed (prescaler was not reset)
  +fix: woz file info properties not correctly propagated to flg variable
  +fix: harvey ball to be fixed
04.11.24: v0.72
  +fix: directory with name of 1 char not read by the emulator
  +fix: PO/po file extension add to the list of extension
  +feat: add menu image (toggle Favorite, unmount, unlink)
  +fix SDIO IRQ for unlink
01.11.24: v0.71
  +feat: config Menu
  +feat: favorites
  +Add: btn repetition for up/down (end of debouncer timer, check for btn state)
  +Adjust: TIM4 period on repeat and back to 400
  +Change: SDIO precaler to 1 (instead of 2) for performance purpose
  +Add: favorites primitives functions
  +refactor: rationnalization of display function
  +add: toggle add/remove favorite from image screen
  +add: favorite parsing on Image Mounting
  +fix: issue with SDIO IRQ on saveConfiguration
  +fix: issue with SDIO IRQ on favoriteSaveConfiguration
  +fix: issue with favorite filename displaying full path
  +fix: missing icon for favorite in ImageScreen
  +add: define.h
  +fix: init chainedlist based screen with 0 and first row selected
  +refactor: display function
31.10.24: v0.69
  +Add PO file support
  +Fix DSK driver getSdAddr 8*512 instead of 16*512, a track in DSK is 4096,8192
30.10.24: v0.68
  + Fix Woz v1.0 file reading (wrong offset to read the double byte and conversion to uint_16)
28.10.24: v0.67
  + Fix Reset on startup
  + Fix Lack of display at startup (same issue as Reset)
  + Fix lost mount ref (due to IRQ disable between read)
28.10.24: v0.66
  + Fix NIC Drive not handling the right number of block to read
  + Mod the readme 
24.10.24:
  + Modification of the flow from mount to beaming
  + Remove hardcoded critical variable
  + Adding new MainMenu screen 

24.10.23: 
  +Change Makefile, 
  +Add option for bootloader,
  +Modifiy issue with button order,
  +Change timer setting to match USB max setting / 96Mhz
  +Add UF2 file management with dedicated bootloader
  +Add (experimental mkfs option)
*/

/* USER CODE END Header */
/* Includes ------------------------------------------------------------------*/
#include "main.h"
#include "fatfs.h"

/* USER CODE BEGIN Includes */

#include "display.h"
#include "list.h"

#include "emul_smartport.h"
#include "emul_diskii.h"
#include "configFile.h"
#include "favorites.h"
#include "log.h"

/* USER CODE END Includes */

/* USER CODE BEGIN PM */
#ifdef A2F_MODE
#pragma message("...building with A2F mode!")
#endif
/* USER CODE END PM */

I2C_HandleTypeDef hi2c1;
DMA_HandleTypeDef hdma_i2c1_tx;

SD_HandleTypeDef hsd;
DMA_HandleTypeDef hdma_sdio_rx;
DMA_HandleTypeDef hdma_sdio_tx;

TIM_HandleTypeDef htim1;
TIM_HandleTypeDef htim2;
TIM_HandleTypeDef htim3;
TIM_HandleTypeDef htim4;

UART_HandleTypeDef huart1;

/* USER CODE BEGIN PV */
volatile unsigned int *DWT_CYCCNT   = (volatile unsigned int *)0xE0001004;
volatile unsigned int *DWT_CONTROL  = (volatile unsigned int *)0xE0001000;
volatile unsigned int *DWT_LAR      = (volatile unsigned int *)0xE0001FB0;
volatile unsigned int *SCB_DHCSR    = (volatile unsigned int *)0xE000EDF0;
volatile unsigned int *SCB_DEMCR    = (volatile unsigned int *)0xE000EDFC;
volatile unsigned int *ITM_TER      = (volatile unsigned int *)0xE0000E00;
volatile unsigned int *ITM_TCR      = (volatile unsigned int *)0xE0000E80;
static int Debug_ITMDebug = 0;
/* USER CODE END PV */

void SystemClock_Config(void);
static void MX_GPIO_Init(void);
static void MX_DMA_Init(void);
static void MX_I2C1_Init(void);
static void MX_USART1_UART_Init(void);
static void MX_TIM3_Init(void);
static void MX_TIM4_Init(void);
static void MX_SDIO_SD_Init(void);
static void MX_TIM2_Init(void);
static void MX_TIM1_Init(void);
static void MX_NVIC_Init(void);
/* USER CODE BEGIN PFP */

/*
* 4 Physical button function
*/
void (*ptrbtnUp)(void *);                                 
void (*ptrbtnDown)(void *);
void (*ptrbtnEntr)(void *);
void (*ptrbtnRet)(void *);

// Hook function for different type emulation
void (*ptrPhaseIRQ)();                                      // Pointer to function managing Ph0 to Ph3
void (*ptrReceiveDataIRQ)();                                // Pointer to Received Data function with WR_DATA
void (*ptrSendDataIRQ)();                                   // Pointer to Send Data function with RD_DATA
void (*ptrWrReqIRQ)();                                      // Pointer to Interrupt function for WR_REQUEST
int (*ptrDeviceEnableIRQ)(uint16_t GPIO_Pin);               // Pointer to Interrupt function for DEVICE_ENABLE
enum STATUS (*ptrUnmountImage)();                           
enum STATUS (*ptrMountImagefile)(char * filename);
void (*ptrMainLoop)();                                      // Main Loop function pointer
void (*ptrInit)();                                          // Init function pointer

bool buttonDebounceState=true;

FATFS fs;                                                   // fatfs global variable <!> do not remount witihn a function the fatfs otherwise it breaks the rest
long database=0;                                            // start of the data segment in FAT
int csize=0;                                                // Cluster size

extern char currentFullPath[MAX_FULLPATH_LENGTH];                    // current path from root
extern char currentPath[MAX_PATH_LENGTH];                            // current directory name max 64 char
extern char currentFullPathImageFilename[MAX_FULLPATHIMAGE_LENGTH];  // fullpath from root image filename
extern char tmpFullPathImageFilename[MAX_FULLPATHIMAGE_LENGTH];      // fullpath from root image filename

uint8_t flgSoundEffect=0;                                   // Activate Buzze
uint8_t bootMode=0;
uint8_t emulationType=0;
uint8_t bootImageIndex=0;
list_t * dirChainedList;


// DEBUG BLOCK

unsigned long t1,t2,diff1;   

/* USER CODE END PFP */

/* USER CODE BEGIN 0 */


void EnableTiming(void){
  if ((*SCB_DHCSR & 1) && (*ITM_TER & 1)) // Enabled?
    Debug_ITMDebug = 1;

  *SCB_DEMCR |= 0x01000000;
  *DWT_LAR = 0xC5ACCE55;                                    // enable access
  *DWT_CYCCNT = 0;                                          // reset the counter
  *DWT_CONTROL |= 1 ;                                       // enable the counter
}

int ui16NothingHook(uint16_t GPIO_Pin){
  return 0;
}

enum STATUS statusNothingHook(char * ptr){
  return RET_ERR;
}

void nothingHook(void*){
  return;
}

/**
  * @brief Button debouncer that reset the Timer 4
  * @param GPIO
  * @retval None
  */
void debounceBtn(int GPIO){

  buttonDebounceState=false;
  TIM4->CNT=0;
  TIM4->CR1 |= TIM_CR1_CEN;
  processBtnInterrupt(GPIO);
}

/**
  * @brief TIMER4 IRQ Handler, manage the debouncer of the control button (UP,DWN,RET,ENTER)
  * @param 
  * @retval None
  */
void TIM4_IRQHandler(void){

  if (TIM4->SR & TIM_SR_UIF){
    buttonDebounceState = true;
    log_debug("debounced\n");
    if(HAL_GPIO_ReadPin(BTN_UP_GPIO_Port, BTN_UP_Pin)){
      debounceBtn(BTN_UP_Pin);
      TIM4->ARR=200;                                      // Manage repeat acceleration
    }       
    else if(HAL_GPIO_ReadPin(BTN_DOWN_GPIO_Port, BTN_DOWN_Pin)){
      debounceBtn(BTN_DOWN_Pin);
      TIM4->ARR=200;                                      // Manage repeat acceleration
    }
    else{
      TIM4->ARR=400;                                      // No repeat back to normal timer value
    }
  }
  TIM4->SR = 0;
}

/**
  * @brief TIMER 3 IRQ Interrupt is handling the reading process
  * @param None
  * @retval None
  */
void TIM3_IRQHandler(void){

  if (TIM3->SR & TIM_SR_UIF){
    TIM3->SR &= ~TIM_SR_UIF;                              // Clear the overflow interrupt 
    ptrSendDataIRQ();
  }else if (TIM3->SR & TIM_SR_CC1IF){                     // Pulse compare interrrupt on Channel 1
    RD_DATA_GPIO_Port->BSRR=1U <<16;                      // Reset the RD_DATA GPIO
    TIM3->SR &= ~TIM_SR_CC1IF;                            // Clear the compare interrupt flag
  }else
    TIM3->SR = 0;
}

volatile enum FS_STATUS fsState=READY;

/**
  * @brief TIMER 2 IRQ Handler is managing the WR_DATA Signal from the A2,       
  * @param (void)
  * @retval None
  */
void TIM2_IRQHandler(void){

  if (TIM2->SR & TIM_SR_UIF){ 
    TIM2->SR &= ~TIM_SR_UIF;                                                  // Reset the Interrupt
    //HAL_GPIO_WritePin(DEBUG_GPIO_Port,DEBUG_Pin,GPIO_PIN_RESET);
    HAL_GPIO_WritePin(RD_DATA_GPIO_Port,RD_DATA_Pin,GPIO_PIN_RESET);

  }else if (TIM2->SR & TIM_SR_CC2IF){                                        // The count & compare is on channel 2 to avoid issue with ETR1
    //HAL_GPIO_WritePin(DEBUG_GPIO_Port,DEBUG_Pin,GPIO_PIN_RESET);
    
    TIM2->SR &= ~TIM_SR_CC2IF;                                                // clear the count & compare interrupt
    ptrReceiveDataIRQ();

  }else{
    //HAL_GPIO_WritePin(DEBUG_GPIO_Port,DEBUG_Pin,GPIO_PIN_RESET);
    HAL_GPIO_WritePin(RD_DATA_GPIO_Port,RD_DATA_Pin,GPIO_PIN_RESET);
    TIM2->SR=0;
  }    
}


/**
  * @brief Adjust Enable IRQ for reading process to avoid jitter / delay / corrupted data 
  * @param None
  * @retval None
  */
void irqReadTrack(){

  HAL_NVIC_DisableIRQ(TIM2_IRQn);
  HAL_NVIC_EnableIRQ(TIM3_IRQn);
  HAL_NVIC_EnableIRQ(TIM4_IRQn);
}
/**
  * @brief Adjust Enable IRQ for writting process to avoid jitter / delay / corrupted data
  * @param None
  * @retval None
  */
void irqWriteTrack(){

  HAL_NVIC_EnableIRQ(TIM2_IRQn);
  HAL_NVIC_DisableIRQ(TIM3_IRQn);
  HAL_NVIC_DisableIRQ(TIM4_IRQn);
}

/**
  * @brief Adjust Enable IRQ for idle process to avoid jitter / delay / corrupted data
  * @param None
  * @retval None
  */
void irqWIdle(){

  HAL_NVIC_DisableIRQ(TIM2_IRQn);
  HAL_NVIC_EnableIRQ(TIM3_IRQn);
  HAL_NVIC_EnableIRQ(TIM4_IRQn);
  //HAL_NVIC_EnableIRQ(EXTI15_10_IRQn);
}
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
int main(void){

  /* USER CODE BEGIN 1 */

  FRESULT fres;
  /* USER CODE END 1 */

  /* MCU Configuration--------------------------------------------------------*/

  /* Reset of all peripherals, Initializes the Flash interface and the Systick. */
  HAL_Init();

  /* Configure the system clock */
  SystemClock_Config();

  /* USER CODE BEGIN SysInit */


  // --------------------------------------------------------------------
  // ptr declaration needs to be before NVIC init
  // --------------------------------------------------------------------

  ptrPhaseIRQ=nothingHook;
  ptrReceiveDataIRQ=nothingHook;
  ptrSendDataIRQ=nothingHook;
  ptrWrReqIRQ=nothingHook;
  ptrDeviceEnableIRQ=ui16NothingHook;
  ptrMainLoop=nothingHook;
  ptrUnmountImage=statusNothingHook;
  ptrMountImagefile=statusNothingHook;
  ptrInit=nothingHook;
  
  /* USER CODE END SysInit */

  /* Initialize all configured peripherals */
  MX_GPIO_Init();
  MX_DMA_Init();
  MX_I2C1_Init();
  MX_USART1_UART_Init();
  MX_TIM3_Init();
  MX_FATFS_Init();
  MX_TIM4_Init();
  MX_SDIO_SD_Init();
  MX_TIM2_Init();
  MX_TIM1_Init();

  /* Initialize interrupts */
  MX_NVIC_Init();
  /* USER CODE BEGIN 2 */

  log_set_level(LOG_INFO);

  currentFullPathImageFilename[0]=0x0;
  currentFullPath[0]=0x0;
  tmpFullPathImageFilename[0]=0x0;

  log_info("************** BOOTING ****************");                      // Data to send
  log_info("**     This is the sound of sea !    **");
  log_info("***************************************");
  
  initSplashScreen();                                                       // I2C Screen init                  
                                            
  HAL_Delay(SPLASHSCREEN_DURATION);

  EnableTiming();                                                           // Enable WatchDog to get precise CPU Cycle counting

  TIM1->PSC=1000;

  int T2_DIER=0x0;
  T2_DIER|=TIM_DIER_CC2IE;
  T2_DIER|=TIM_DIER_UIE;
  TIM2->DIER|=T2_DIER;                                                      // Enable Output compare Interrupt
  
  int T4_DIER=0x0;
  T4_DIER|=TIM_DIER_CC2IE;
  T4_DIER|=TIM_DIER_UIE;
  TIM4->DIER|=T4_DIER;   

  int dier=0x0;
  dier|=TIM_DIER_CC1IE;
  dier|=TIM_DIER_UIE;
  TIM3->DIER=dier;
  
  processSdEject(SD_EJECT_Pin);
  
  ptrDeviceEnableIRQ(DEVICE_ENABLE_Pin);


  dirChainedList = list_new();                                              // ChainedList to manage File list in current path                                                     

  fres = f_mount(&fs, "", 1);                                       
  
  csize=fs.csize;
  database=fs.database;
  char * imgFile=NULL;

  // --------------------------------------------------------------------
  // Load configuration variable
  // --------------------------------------------------------------------

  if (fres == FR_OK){

    if (loadConfigFile()==RET_ERR){
      log_error("loading configFile error");
      setConfigFileDefaultValues();
      if (saveConfigFile()!=RET_OK){
        log_error("Error in saving default to configFile");
      }else{
        log_info("init default and save configFile");
      }
    }else{
      getFavorites();
      buildLstFromFavorites();
      
      if (getConfigParamUInt8("bootMode",&bootMode)==RET_ERR)
        log_error("error getting bootMode from Config");
      else 
        log_info("bootMode=%d",bootMode);

      if (getConfigParamUInt8("emulationType",&emulationType)==RET_ERR)
        log_error("error getting emulationType from Config");
      else 
        log_info("emulationType=%d",emulationType);
      
      if (getConfigParamUInt8("bootImageIndex",&bootImageIndex)==RET_ERR)
        log_warn("warning getting bootImageIndex from Config");
      else 
        log_info("bootImageIndex=%d",bootImageIndex);

      
      if (getConfigParamUInt8("soundEffect",&flgSoundEffect)==RET_ERR)
        log_error("error getting soundEffect from Config");
      else 
        log_info("soundEffect=%d",flgSoundEffect);

    }

    imgFile=(char*)getConfigParamStr("lastFile");
    char * tmp=(char*)getConfigParamStr("currentPath");
    
    if (tmp)
      sprintf(currentFullPath,"%s",tmp);
    else
      currentFullPath[0]=0x0;
    
    if (imgFile!=NULL){
      log_info("lastFile:%s",imgFile);
      sprintf(tmpFullPathImageFilename,"%s",imgFile);
    }

    walkDir(currentFullPath);

  }else{
    log_error("Error mounting sdcard %d",fres);
  }

  // --------------------------------------------------------------------
  // Prepate emulation mode
  // --------------------------------------------------------------------
  //emulationType=DISKII;
  //emulationType=SMARTPORTHD;

  switch(emulationType){
    case DISKII:
      log_info("loading DiskII emulation");
      ptrPhaseIRQ=DiskIIPhaseIRQ;
      ptrReceiveDataIRQ=DiskIIReceiveDataIRQ;
      ptrSendDataIRQ=DiskIISendDataIRQ;
      ptrWrReqIRQ=DiskIIWrReqIRQ;
      ptrDeviceEnableIRQ=DiskIIDeviceEnableIRQ;
      ptrMainLoop=DiskIIMainLoop;
      ptrUnmountImage=DiskIIUnmountImage;
      ptrMountImagefile=DiskIIMountImagefile;
      ptrInit=DiskIIInit;
      break;

    case DISK35:
      log_info("loading Disk3.5 emulation");
      break;

    case SMARTPORTHD:
      log_info("loading SmartPortHD emulation");
      ptrPhaseIRQ=SmartPortPhaseIRQ;
      ptrReceiveDataIRQ=SmartPortReceiveDataIRQ;
      ptrSendDataIRQ=SmartPortSendDataIRQ;
      ptrWrReqIRQ=SmartPortWrReqIRQ;
      //ptrDeviceEnableIRQ=NULL;
      ptrMainLoop=SmartPortMainLoop;
      //ptrUnmountImage=NULL;
      //ptrMountImagefile=SmartPortMountImage;
      ptrInit=SmartPortInit;
      break;

  }

  // --------------------------------------------------------------------
  // Init emulation
  // --------------------------------------------------------------------

  ptrInit();

  // --------------------------------------------------------------------
  // Execute emulation
  // --------------------------------------------------------------------

  ptrMainLoop();

  while(1){};


  /* USER CODE END 2 */

  /* Infinite loop */
}

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
/* USER CODE BEGIN 4 */
/**
  * @brief  Callback function for External interrupt
  * @param  GPIO_Pin
  * @retval None
  */
void HAL_GPIO_EXTI_Callback(uint16_t GPIO_Pin){

  //printf("startr here 0 %d\n",GPIO_Pin);
  if( GPIO_Pin == STEP0_Pin   ||               // Step 0 PA0
      GPIO_Pin == STEP1_Pin   ||               // Step 1 PA1
      GPIO_Pin == STEP2_Pin   ||               // Step 2 PA2
      GPIO_Pin == STEP3_Pin                    // Step 3 PA3
  
  ){            

    ptrPhaseIRQ();
    
  }else if (GPIO_Pin==DEVICE_ENABLE_Pin){
    ptrDeviceEnableIRQ(DEVICE_ENABLE_Pin);

  }else if ((GPIO_Pin == BTN_RET_Pin   ||      // BTN_RETURN
            GPIO_Pin == BTN_ENTR_Pin  ||       // BTN_ENTER
            GPIO_Pin == BTN_UP_Pin    ||       // BTN_UP
            GPIO_Pin == BTN_DOWN_Pin           // BTN_DOWN
            ) && buttonDebounceState==true){
    
    debounceBtn(GPIO_Pin);

  }else if (GPIO_Pin == WR_REQ_Pin){
    
    ptrWrReqIRQ();
    
  }else {
      __NOP();
  }
}


/**
  * @brief  Retargets the C library printf function to the USART.
  * @param  None
  * @retval None
  */
PUTCHAR_PROTOTYPE{
  /* Place your implementation of fputc here */
  /* e.g. write a character to the USART1 and Loop until the end of transmission */
  
  HAL_UART_Transmit(&huart1, (uint8_t *)&ch, 1, 0xFFFF);  
  return ch;
}
/* USER CODE END 4 */
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


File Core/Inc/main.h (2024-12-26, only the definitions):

#define PUTCHAR_PROTOTYPE int __io_putchar(int ch)
#define PUTCHAR_PROTOTYPE int fputc(int ch, FILE *f)
#define BTN_DOWN_Pin GPIO_PIN_13
#define BTN_DOWN_GPIO_Port GPIOC
#define BTN_DOWN_EXTI_IRQn EXTI15_10_IRQn
#define BTN_UP_Pin GPIO_PIN_14
#define BTN_UP_GPIO_Port GPIOC
#define BTN_UP_EXTI_IRQn EXTI15_10_IRQn
#define BTN_ENTR_Pin GPIO_PIN_15
#define BTN_ENTR_GPIO_Port GPIOC
#define BTN_ENTR_EXTI_IRQn EXTI15_10_IRQn
#define STEP0_Pin GPIO_PIN_0
#define STEP0_GPIO_Port GPIOA
#define STEP0_EXTI_IRQn EXTI0_IRQn
#define STEP1_Pin GPIO_PIN_1
#define STEP1_GPIO_Port GPIOA
#define STEP1_EXTI_IRQn EXTI1_IRQn
#define STEP2_Pin GPIO_PIN_2
#define STEP2_GPIO_Port GPIOA
#define STEP2_EXTI_IRQn EXTI2_IRQn
#define STEP3_Pin GPIO_PIN_3
#define STEP3_GPIO_Port GPIOA
#define STEP3_EXTI_IRQn EXTI3_IRQn
#define DEVICE_ENABLE_Pin GPIO_PIN_4
#define DEVICE_ENABLE_GPIO_Port GPIOA
#define DEVICE_ENABLE_EXTI_IRQn EXTI4_IRQn
#define WR_DATA_Pin GPIO_PIN_7
#define WR_DATA_GPIO_Port GPIOA
#define RD_DATA_Pin GPIO_PIN_0
#define RD_DATA_GPIO_Port GPIOB
#define WR_PROTECT_Pin GPIO_PIN_2
#define WR_PROTECT_GPIO_Port GPIOB
#define BTN_RET_Pin GPIO_PIN_12
#define BTN_RET_GPIO_Port GPIOB
#define BTN_RET_EXTI_IRQn EXTI15_10_IRQn
#define SD_EJECT_Pin GPIO_PIN_13
#define SD_EJECT_GPIO_Port GPIOB
#define DEBUG_Pin GPIO_PIN_10
#define DEBUG_GPIO_Port GPIOA
#define WR_REQ_Pin GPIO_PIN_9
#define WR_REQ_GPIO_Port GPIOB
#define WR_REQ_EXTI_IRQn EXTI9_5_IRQn
#define AB_Pin GPIO_PIN_8
#define AB_GPIO_Port GPIOB
#define ENCODER_A_Pin GPIO_PIN_1
#define ENCODER_A_GPIO_Port GPIOB
#define ENCODER_B_Pin GPIO_PIN_10
#define ENCODER_B_GPIO_Port GPIOB

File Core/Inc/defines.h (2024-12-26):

#define _VERSION "v0.79.1"

#define SPLASHSCREEN_DURATION 1000

#define MAX_FAVORITES 10

#define MAX_FILENAME_LENGTH 64
#define MAX_FULLPATH_LENGTH 256
#define MAX_PATH_LENGTH 64
#define MAX_FULLPATHIMAGE_LENGTH 320 
#define JSON_BUFFER_SIZE 2048

#define CONFIGFILE_NAME "/sdiskConfig.json"

#define SCREEN_MAX_LINE_ITEM 4

#define RAW_SD_TRACK_SIZE 8192                          // Maximuum track size on NIC & WOZ to load from SD
#define WEAKBIT 1

#define MAX_TRACK 59                                    // Max Number of track for a given Apple II Floppy,

#define MAX_PARTITIONS  4                               // Number of 32MB Prodos partions supported
#define SP_PKT_SIZE     604
// SMARTPORT MESSAGE OFFSET
/*

The following packet 
shows the timing and content of a SmartPort READBLOCK call.  For further 
explanation of the structure, please see the Apple IIGS Hardware Reference and 
the Apple IIGS Firmware Reference.


DATA            MNEMONIC  DESCRIPTION                           TIME
(SmartPort Bus)           (Relative)
_____________________________________________________________________________
FF              SYNC      SELF SYNCHRONIZING BYTES              0                   0
3F              :         :                                     32 micro Sec.       1
CF              :         :                                     32 micro Sec.       2
F3              :         :                                     32 micro Sec.       3
FC              :         :                                     32 micro Sec.       4
FF              :         :                                     32 micro Sec.       5
C3              PBEGIN    MARKS BEGINNING OF PACKET             32 micro Sec.       6
81              DEST      DESTINATION UNIT NUMBER               32 micro Sec.       7
80              SRC       SOURCE UNIT NUMBER                    32 micro Sec.       8
80              TYPE      PACKET TYPE FIELD                     32 micro Sec.       9
80              AUX       PACKET AUXILLIARY TYPE FIELD          32 micro Sec.      10
80              STAT      DATA STATUS FIELD                     32 micro Sec.      11
82              ODDCNT    ODD BYTES COUNT                       32 micro Sec.      12
81              GRP7CNT   GROUP OF 7 BYTES COUNT                32 micro Sec.      13
80              ODDMSB    ODD BYTES MSB's                       32 micro Sec.      14
81              COMMAND   1ST ODD BYTE = Command Byte           32 micro Sec.      15
83              PARMCNT   2ND ODD BYTE = Parameter Count        32 micro Sec.      16
80              GRP7MSB   MSB's FOR 1ST GROUP OF 7              32 micro Sec.      17
80              G7BYTE1   BYTE 1 FOR 1ST GROUP OF 7             32 micro Sec.      18
98              G7BYTE2   BYTE 2 FOR 1ST GROUP OF 7             32 micro Sec.      19
82              G7BYTE3   BYTE 3 FOR 1ST GROUP OF 7             32 micro Sec.      20
80              G7BYTE4   BYTE 4 FOR 1ST GROUP OF 7             32 micro Sec.      21
80              G7BYTE5   BYTE 5 FOR 1ST GROUP OF 7             32 micro Sec.      22
80              G7BYTE5   BYTE 6 FOR 1ST GROUP OF 7             32 micro Sec.      23
80              G7BYTE6   BYTE 7 FOR 1ST GROUP OF 7             32 micro Sec.      24
BB              CHKSUM1   1ST BYTE OF CHECKSUM                  32 micro Sec.      25
EE              CHKSUM2   2ND BYTE OF CHECKSUM                  32 micro Sec.      26
C8              PEND      PACKET END BYTE                       32 micro Sec.      27
00              FALSE     FALSE IWM WRITE TO CLEAR REGISTER     32 micro Sec.      28
_____________________________________________________________________________
*/
#define SP_PBEGIN   0
#define SP_DEST     1
#define SP_SRC      2
#define SP_TYPE     3
#define SP_AUX      4
#define SP_STAT     5
#define SP_ODDCNT   6
#define SP_GRP7CNT  7
#define SP_ODDMSB   8
#define SP_COMMAND  9
#define SP_PARMCNT  10
#define SP_GRP7MSB  11
#define SP_G7BYTE1  12

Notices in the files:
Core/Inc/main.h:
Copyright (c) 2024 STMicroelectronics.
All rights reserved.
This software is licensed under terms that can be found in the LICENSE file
